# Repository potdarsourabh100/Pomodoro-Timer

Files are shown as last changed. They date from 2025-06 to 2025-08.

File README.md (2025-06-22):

# Pomodoro Timer (STM32 + TM1637 + 18650 Li-ion)

A compact and handheld Pomodoro Timer built using an STM32 microcontroller, TM1637 display, 2 tactile switches, and a buzzer. It is powered by dual 18650 Li-ion cells with a 2S BMS and includes USB charging support.

---

## Pomodoro Timer Flowchart

```text
+----------------------+
|   Start Application |
+----------------------+
           |
           v
+----------------------+
|  Set Work Duration   |<------+
|   (e.g., 25 mins)    |       |
+----------------------+       |
           |                   |
           v                   |
+----------------------+       |
|    Start Work Timer  |       |
+----------------------+       |
           |                   |
           v                   |
+----------------------+       |
|   Countdown Work     |       |
|   Time Every Second  |       |
+----------------------+       |
           |                   |
           v                   |
+----------------------+       |
|  Work Time Finished? |--No--+
+----------------------+
           |
          Yes
           |
           v
+----------------------+
| Play Alarm / Notify |
+----------------------+
           |
           v
+----------------------+
|  Increment Pomodoro  |
|     Count (+1)       |
+----------------------+
           |
           v
+----------------------+
| Pomodoro Count % 4 = 0? |
+----------------------+
       | Yes          | No
       v              v
+----------------+  +----------------------+
| Long Break     |  | Short Break         |
| (15-30 mins)   |  | (5 mins)            |
+----------------+  +----------------------+
       |                   |
       v                   v
+----------------------+  +----------------------+
|  Start Break Timer   |  |  Start Break Timer   |
+----------------------+  +----------------------+
           |                   |
           v                   v
+----------------------+  +----------------------+
| Countdown Break Time |  | Countdown Break Time |
+----------------------+  +----------------------+
           |                   |
           v                   v
+----------------------+  +----------------------+
| Break Time Finished? |  | Break Time Finished? |
+----------------------+  +----------------------+
           |                   |
          Yes                 Yes
           |                   |
           v                   v
+----------------------+
|     Back to Work     |
+----------------------+
           |
           v
     (Repeat Cycle)
```
---

## 🧠 Features

- ⏱️ Pomodoro Mode(P): 25 minutes of focus time
- ☕ Short Break(S): 5 minutes
- 😌 Long Break(L): 15 minutes (after 4 Pomodoros)
- 2 Push Buttons:
  - Button 1: Start/Stop/Reset
  - Button 2: Cycle Modes (P/S/L)
- Buzzer for notifications (end of session, low battery)
- Powered by 2x 18650 Li-ion with BMS protection
- USB Charging (Micro-USB/USB-C)
- TM1637 4-digit 7-segment display

---

## 📦 Hardware Used

| Component | Description |
|---|---|
| STM32 MCU | STM32F0xx / STM32G0xx series |
| Display | TM1637 4-digit 7-segment module |
| Buzzer | Active piezo buzzer |
| Switches | 2x Tactile push buttons |
| Battery | 2x 18650 Li-ion cells |
| USB Charging | TP4056-based charger (5V input) |

---

## 🔧 Build Instructions

1. Assemble all hardware components as per the schematic.
2. Flash the firmware to the STM32 using ST-Link.
3. Power the system using a battery or USB.
4. Use Button 1 to start/stop/reset the timer.
5. Use Button 2 to switch between Pomodoro, Short, and Long Break modes.

---

## 📌 To-Do / Enhancements

- [ ] Add various tones for notifications
- [ ] Add BLE support for app notifications
- [ ] Configurable timer durations via USB
- [ ] Battery monitoring via ADC
- [ ] Low-power sleep mode
- [ ] Pocket-sized, portable enclosure

---

## 📜 License

This project is open-source under the MIT License.

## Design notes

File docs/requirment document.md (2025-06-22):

## 1. Project Overview
A handheld Pomodoro Timer device to help users manage time effectively using the Pomodoro technique. The device will display a countdown timer on a TM1637 4-digit display, accept input through two push buttons, provide audible alerts via a buzzer, and be powered by a rechargeable 2-cell 18650 Li-ion battery with BMS. USB connectivity will be used for charging and data communication.

## 2. Objective
To develop a compact, portable, and user-friendly Pomodoro Timer that offers a simple user interface and effective time tracking with minimal hardware complexity.
```text
+----------------------+
|   Start Application |
+----------------------+
           |
           v
+----------------------+
|  Set Work Duration   |<------+
|   (e.g., 25 mins)    |       |
+----------------------+       |
           |                   |
           v                   |
+----------------------+       |
|    Start Work Timer  |       |
+----------------------+       |
           |                   |
           v                   |
+----------------------+       |
|   Countdown Work     |       |
|   Time Every Second  |       |
+----------------------+       |
           |                   |
           v                   |
+----------------------+       |
|  Work Time Finished? |--No--+
+----------------------+
           |
          Yes
           |
           v
+----------------------+
| Play Alarm / Notify |
+----------------------+
           |
           v
+----------------------+
|  Increment Pomodoro  |
|     Count (+1)       |
+----------------------+
           |
           v
+----------------------+
| Pomodoro Count % 4 = 0? |
+----------------------+
       | Yes          | No
       v              v
+----------------+  +----------------------+
| Long Break     |  | Short Break         |
| (15-30 mins)   |  | (5 mins)            |
+----------------+  +----------------------+
       |                   |
       v                   v
+----------------------+  +----------------------+
|  Start Break Timer   |  |  Start Break Timer   |
+----------------------+  +----------------------+
           |                   |
           v                   v
+----------------------+  +----------------------+
| Countdown Break Time |  | Countdown Break Time |
+----------------------+  +----------------------+
           |                   |
           v                   v
+----------------------+  +----------------------+
| Break Time Finished? |  | Break Time Finished? |
+----------------------+  +----------------------+
           |                   |
          Yes                 Yes
           |                   |
           v                   v
+----------------------+
|     Back to Work     |
+----------------------+
           |
           v
     (Repeat Cycle)
```

## 3. Hardware Requirements
### 3.1 Core Components

|Component	 |Description |
|---|---|
|MCU	 |STM32 (STM32F0xx/G0xx preferred for low power) |
|Display	 |TM1637 4-digit 7-segment display module |
|Switches	 |2 tactile push buttons |  
|Buzzer	 |Active piezo buzzer |
|Battery	 |2 x 18650 Li-ion cells |
|Battery |Protection	2S BMS module |
|Charging	 |Micro-USB or USB-C port with TP4056-based charging IC|

Enclosure	Handheld ergonomic plastic casing (3D printed or off-the-shelf)
## 4. Functional Requirements
### 4.1 Timer Operation
- Pomodoro Duration: 25 minutes of focused work
- Break Duration:
  - Short Break: 5 minutes
  - Long Break: 15 minutes (after every 4 Pomodoros)
- User Input:
  - Button 1 (Start/Stop/Reset):
    - Short Press: Start/Stop timer
    - Long Press (>2s): Reset current session
  - Button 2 (Mode Switch):
- Cycle between Pomodoro, Short Break, Long Break
- Confirmation after 2s timeout or button press
### 4.2 Display Behavior (TM1637)
- Show countdown in MM:SS format.
- Display P, S, or L in the first digit (blinking) to indicate Pomodoro, Short break, or Long break respectively (if applicable).
- When timer is paused, display should blink.
- Show done or ---- when timer ends.
### 4.3 Sound Notifications
- Short beep every minute for feedback (optional).
- Long beep (2s) at the end of each timer.
- Continuous short beeps for 5s as final notification (optional).
### 4.4 Power Management
- Powered by 2x 18650 cells in series.
- 2S BMS to protect from over-voltage, over-discharge, and short-circuit.
- Battery voltage monitoring via ADC to indicate a low battery.
- A low battery warning on display and a buzzer beep pattern.
- Auto shutdown when battery is critically low.
### 4.5 Charging and USB Interface
- USB port for: Charging the batteries (5V input)
- Future provision: serial communication for log extraction or timer configuration
- LED indicator for charging (charging/red, full/green)
### 4.6 Ergonomics
- Device should:
  - Be compact and handheld (approx. 100mm x 60mm x 30mm)
  - Use minimal buttons for ease of use
  - Have an accessible USB port and clear visibility of the display
## 5. Non-Functional Requirements
### 5.1 Performance
- Timer precision: ±1 second over 25 minutes
- Debouncing: Software-based for all buttons
- Startup Time: <2 seconds
- The buzzer should not exceed 80 dB SPL at 10cm
### 5.2 Power Efficiency
- Sleep mode when idle
- Wake up on button press
- Total standby current <500 µA
### 5.3 Environmental
- Operating temperature: 0°C to 50°C
- Humidity: 20–85% RH, non-condensing
## 6. Future Enhancements (Optional)
- Vibration motor for silent notification
- Bluetooth interface for app connectivity
- OLED display for more detailed status
- Custom timer settings via serial interface or USB config tool
## 7. Deliverables
- Schematics and PCB design files
- Firmware source code (with comments and documentation)
- 3D design files for enclosure
- Test report for all functional cases
- User manual (1-page quick start)

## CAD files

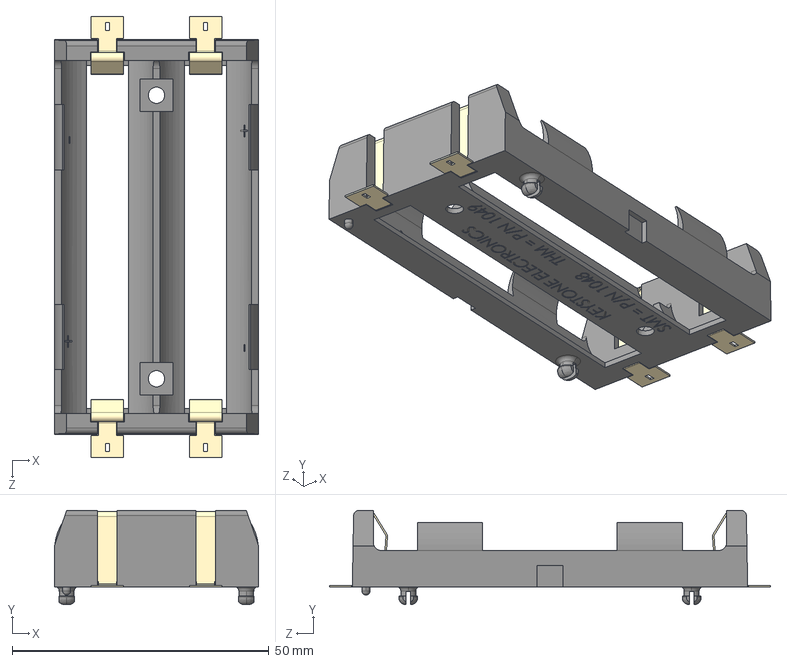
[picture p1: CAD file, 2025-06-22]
hardware/1048/1048.step
39.8 x 18.3 x 86.0 mm

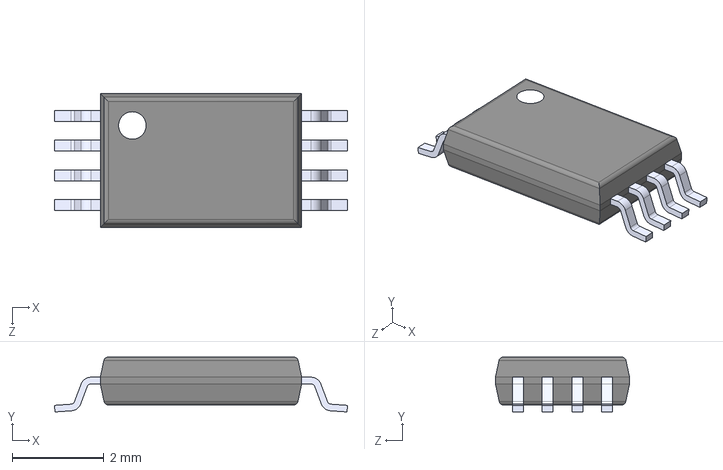
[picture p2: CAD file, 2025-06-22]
hardware/FS8205A/FS8205A.step
6.40 x 1.20 x 2.93 mm

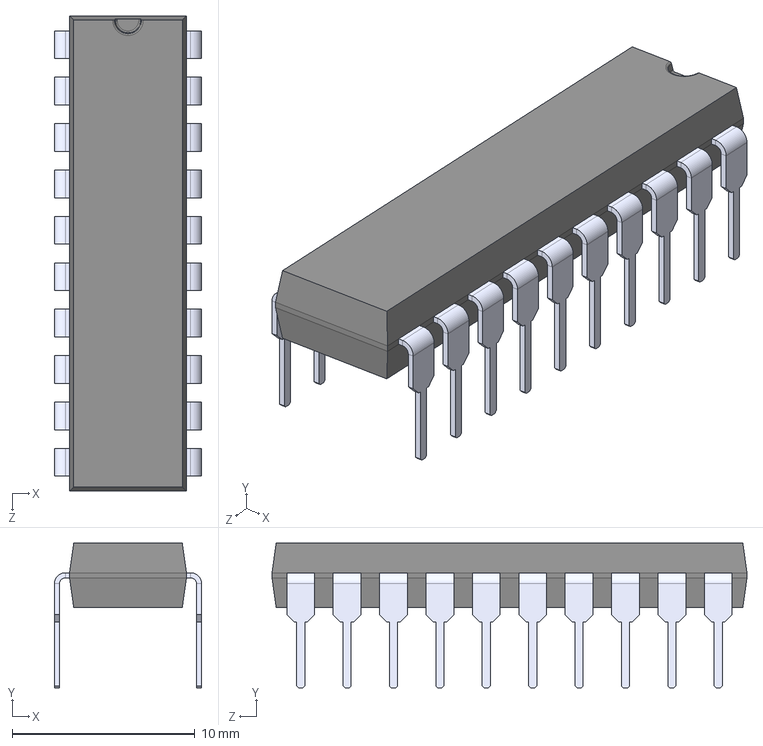
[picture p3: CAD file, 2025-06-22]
hardware/TM1637/TM1637.step
8.06 x 7.91 x 26.0 mm

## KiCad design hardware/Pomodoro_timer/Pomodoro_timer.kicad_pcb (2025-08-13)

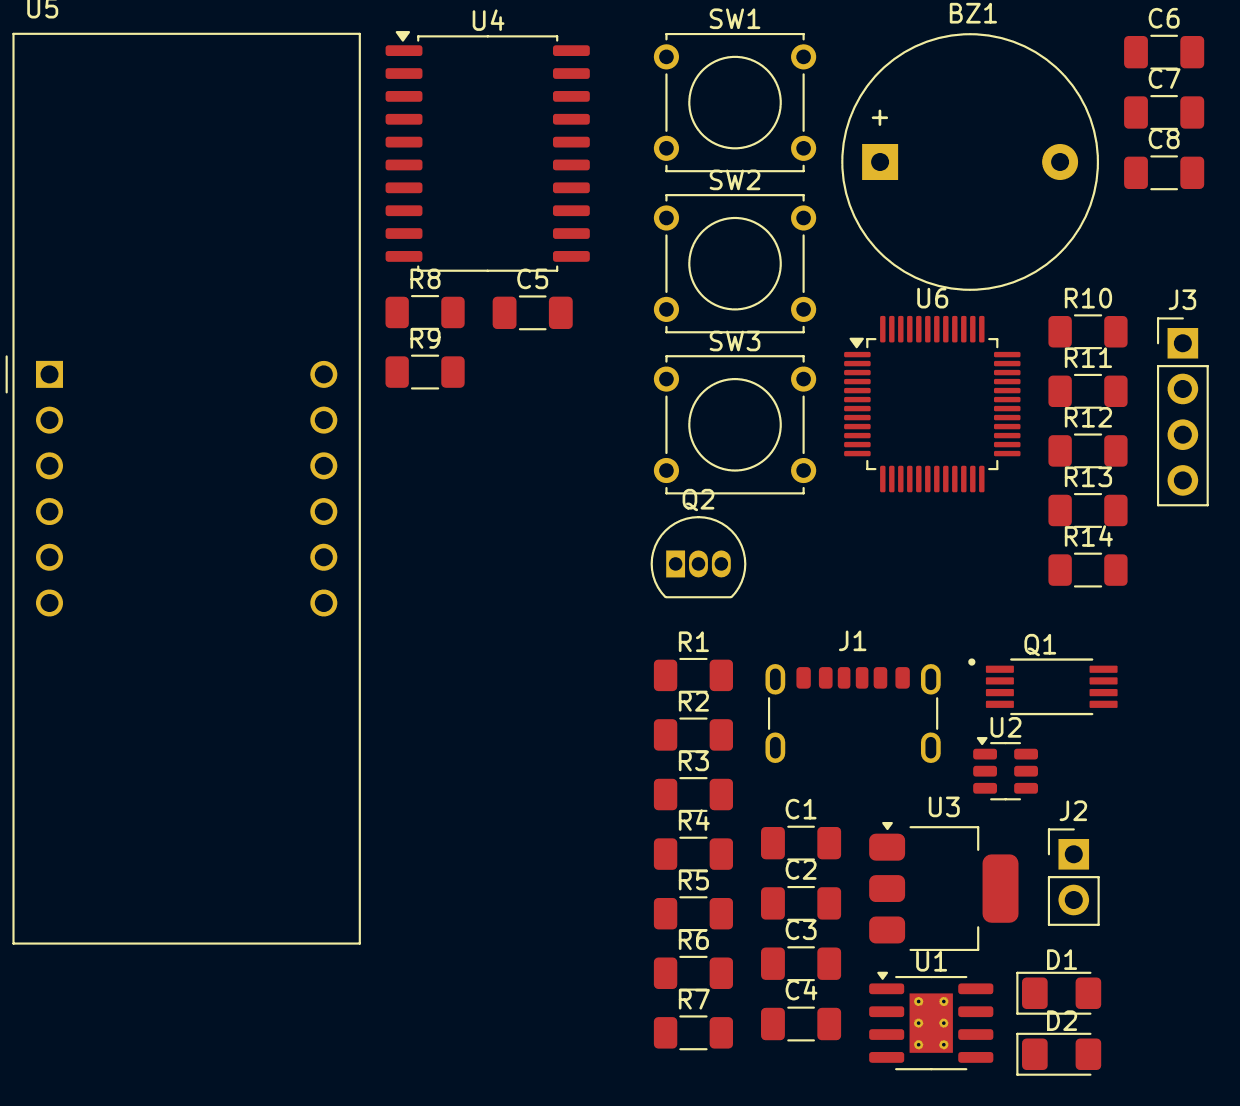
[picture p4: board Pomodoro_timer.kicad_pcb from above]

Board: 2 copper layers, 39 parts (0 on the bottom side), 38 nets, no tracks yet.

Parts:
BZ1: Buzzer; Buzzer_D14mm_H7mm_P10mm
C1, C3, C4, C5, C6, C7, C8: 100nF; C_1206_3216Metric_Pad1.33x1.80mm_HandSolder
C2: 10uF; C_1206_3216Metric_Pad1.33x1.80mm_HandSolder
D1: RED; LED_1206_3216Metric_Pad1.42x1.75mm_HandSolder
D2: GRN; LED_1206_3216Metric_Pad1.42x1.75mm_HandSolder
J1: USB_C_Receptacle_PowerOnly_6P; USB_C_Receptacle_GCT_USB4125-xx-x_6P_TopMnt_Horizontal
J2: Battery; PinHeader_1x02_P2.54mm_Vertical
J3: Prog_Port; PinHeader_1x04_P2.54mm_Vertical
Q1: FS8205A; SOP65P640X120-8N
Q2: BC516; TO-92_Inline
R1, R2: 5K1; R_1206_3216Metric_Pad1.30x1.75mm_HandSolder
R3, R4, R6, R10: 1K; R_1206_3216Metric_Pad1.30x1.75mm_HandSolder
R5: 1K2; R_1206_3216Metric_Pad1.30x1.75mm_HandSolder
R7: 100; R_1206_3216Metric_Pad1.30x1.75mm_HandSolder
R8, R9, R11, R12, R13, R14: 4K7; R_1206_3216Metric_Pad1.30x1.75mm_HandSolder
SW1, SW2: CTRL_SW; SW_Tactile_Straight_KSA0Axx1LFTR
SW3: FUNC_SW; SW_Tactile_Straight_KSA0Axx1LFTR
U1: TP4056-42-ESOP8; SOIC-8-1EP_3.9x4.9mm_P1.27mm_EP2.41x3.3mm_ThermalVias
U2: DW01A; SOT-23-6
U3: AP2127K-3.3; SOT-223-3_TabPin2
U4: TM1637; SOIC-20W_7.5x12.8mm_P1.27mm
U5: CC56-12EWA; CA56-12EWA
U6: STM32G070CBTx; LQFP-48_7x7mm_P0.5mm

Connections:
+5V: C1.1, D1.2 (A), D2.2 (A), J1.A9 (VBUS), J1.B9 (VBUS), U1.4 (V_{CC}), U1.8 (CE)
CLK: R9.2, U4.18 (CLK), U6.26 (PB14)
DIO: R8.2, U4.17 (DIO), U6.27 (PB15)
GND: C1.2, C2.2, C3.2, C4.2, C5.2, C6.2, C7.2, C8.2, J1.A12 (GND), J1.B12 (GND), J1.S1 (SHIELD), J3.4, Q1.6, Q1.7, Q2.3 (E), R1.1, R2.1, R5.1, R6.1, SW1.1, SW2.2, SW3.2, U1.1 (TEMP), U1.3 (GND), U2.6 (GND), U3.2 (GND), U4.1 (GND), U6.7 (VSS)
unnamed: BZ1.2 (-), Q2.1 (C)
unnamed: D1.1 (K), R3.1
unnamed: D2.1 (K), R4.1
unnamed: J1.A5 (CC1), R2.2
unnamed: J1.B5 (CC2), R1.2
unnamed: C3.1, J2.1, R7.1, U1.5 (BAT), U3.1 (VIN), U3.3 (EN)
unnamed: J2.2, Q1.2, Q1.3
unnamed: Q2.2 (B), R10.2
unnamed: R5.2, U1.2 (PROG)
unnamed: R3.2, U1.7 (~CHRG)
unnamed: R4.2, U1.6 (~STDBY)
unnamed: R6.2, U2.2 (CS)
unnamed: Q1.5, U2.3 (OC)
unnamed: Q1.4, U2.1 (OD)
unnamed: C2.1, R7.2, U2.5 (VCC)
unnamed: U4.15 (GRID1), U5.12 (CC1)
unnamed: U4.14 (GRID2), U5.9 (CC2)
unnamed: U4.13 (GRID3), U5.8 (CC3)
unnamed: U4.12 (GRID4), U5.6 (CC4)
unnamed: U4.2 (SEG1/KS1), U5.11 (a)
unnamed: U4.3 (SEG2/KS2), U5.7 (b)
unnamed: U4.4 (SEG3/KS3), U5.4 (c)
unnamed: U4.5 (SEG4/KS4), U5.2 (d)
unnamed: U4.6 (SEG5/KS5), U5.1 (e)
unnamed: U4.7 (SEG6/KS6), U5.10 (f)
unnamed: U4.8 (SEG7/KS7), U5.5 (g)
unnamed: U4.9 (SEG8/KS8), U5.3 (DPX)
unnamed: R12.1, SW1.2, U6.10 (NRST)
unnamed: R14.1, SW2.1, U6.24 (PB12)
unnamed: R13.1, SW3.1, U6.25 (PB13)
unnamed: R10.1, R11.1, U6.3 (PC15)
PWR: BZ1.1 (+), C4.1, C5.1, C6.1, C7.1, C8.1, J3.3, R8.1, R9.1, R11.2, R12.2, R13.2, R14.2, U4.16 (VDD), U6.4 (VBAT), U6.5 (VREF+), U6.6 (VDD)
SWCLK: J3.1, U6.36 (PA14)
SWDIO: J3.2, U6.35 (PA13)

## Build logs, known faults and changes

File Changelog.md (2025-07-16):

# 📓 CHANGELOG

All notable changes to this project will be documented in this file.

---
## [1.2.2] - 2025-07-16
### 🐞 Bug fix
- The values for cycles changed to 5 correct Logic implemented.
### ⚠️ Warning/Notice
- The pause function is yet to be added.
### 💤 Power/Performance
- Although the initial performance looks good
Power-related activities are yet to be tested thoroughly.
---
## [1.2.0] - 2025-07-14
### 🐞 Bug fix
- The given platform dependencies are removed 
- Buzzer functionalities added
### ⚠️ Warning/Notice
- The pause function is yet to be added.
### 💤 Power/Performance
- Although the initial performance looks good
Power-related activities are yet to be tested thoroughly.

## [1.0.1] - 2025-06-22
### 🐞 Bug fix
- The timer was not performing in the correct mode in the proper order
fixed
### ⚠️ Warning/Notice
- Button-related activities are started.
- The pause function is yet to be added.
- Buzzer hardware not yet added.
### 💤 Power/Performance
- Although the initial performance looks good
Power-related activities are yet to be tested thoroughly.

## [1.0.0] - 2025-06-22
### 🚀 Initial Release
- Core Pomodoro functionality (25/5/15 minute cycles)
### ⚠️ Warning/Notice
- Button-related activities are started.
- The pause function is yet to be added.
- Buzzer hardware not yet added.
### 💤 Power/Performance
- Although the initial performance looks good
Power-related activities are yet to be tested thoroughly.

## Legend

| Emoji  | Meaning |
|---|---|
| ✨ | New feature |
| 🛠️ | Change/Improvement|
| 🐞 | Bug fix |
| 🚀 | Major release |
| ⚠️ | Warning/Notice |
| 💤 | Power/Performance |
| 🔧 | Refactor/Tooling  |

---

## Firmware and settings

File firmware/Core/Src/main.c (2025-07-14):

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
/* Includes ------------------------------------------------------------------*/
#include "main.h"

TIM_HandleTypeDef htim3;

void SystemClock_Config(void);
static void MX_GPIO_Init(void);
static void MX_TIM3_Init(void);
/**
  * @brief  The application entry point.
  * @retval int
  */
int main(void)
{

  /* MCU Configuration--------------------------------------------------------*/

  /* Reset of all peripherals, Initializes the Flash interface and the Systick. */
  HAL_Init();

  /* Configure the system clock */
  SystemClock_Config();

  /* Initialize all configured peripherals */
  MX_GPIO_Init();
  MX_TIM3_Init();
  /* USER CODE BEGIN 2 */

  HAL_Delay(1000);

  /* Set LED for warning */
  HAL_GPIO_WritePin(GPIOC, GPIO_PIN_13, GPIO_PIN_SET);

  /* Set Buzzer OFF*/
  HAL_GPIO_WritePin(GPIOB, GPIO_PIN_9, GPIO_PIN_SET);

  userMain();
  /* USER CODE END 2 */

  /* Infinite loop */
  /* USER CODE BEGIN WHILE */
  while (1)
  {
    /* USER CODE END WHILE */

    /* USER CODE BEGIN 3 */
	  /* The given LED reaches if application functions crashed*/
	  HAL_GPIO_TogglePin(GPIOC, GPIO_PIN_13);
	  HAL_Delay(2000);
  }
  /* USER CODE END 3 */
}

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


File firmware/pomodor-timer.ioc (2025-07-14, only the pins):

Mcu.UserName=STM32F401CCUx
PA0-WKUP.Signal=GPIO_Input
PA1.Signal=GPIO_Input
PA13.Signal=SYS_JTMS-SWDIO
PA14.Signal=SYS_JTCK-SWCLK
PB12.Signal=GPIO_Output
PB13.Signal=GPIO_Output
PB9.Signal=GPIO_Output
PC13-ANTI_TAMP.Signal=GPIO_Output

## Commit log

2025-04-20 Given firmware added with TM1637 drivers & tested with 1 second timer.
2025-04-21 Basic timer functionalities & button operations are verified
2025-04-22 POC verified moving to Hardware design
    [Pomodoro_timer.kicad_pcb, Pomodoro_timer.kicad_sch]
2025-06-22 All pieces for prototype are designed & soldered on PCB.
    The given hardware is working with code.
2025-06-22 ## [1.0.0] - 2025-06-22
    ### 🚀 Initial Release
    - Core Pomodoro functionality (25/5/15 minute cycles)
    ---
    ### ⚠️ Warning/Notice
    - Button-related activities are started.
    - The pause function is yet to be added.
    - Buzzer hardware not yet added.
    ### 💤 Power/Performance
    - Although initial performance looks good
    Power-related activities are yet to be tested thoroughly.
    [main.c, pomodorotimer.c]
2025-06-22 ## [1.0.1] - 2025-06-22
    ### 🐞 Bug fix
    - The timer was not performing correct mode in the proper order
    fixed
    - Although the initial performance looks good
    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
    [pomodorotimer.c]
2025-06-22 Board designing started
    [FS8205A.step, Pomodoro_timer.kicad_sch, Power_Supply.kicad_sch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]
2025-06-22 TM1637 Design started
    [1048.step, Power_Supply.kicad_sch, TM1637.step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]
2025-07-14 ## [1.2.0] - 2025-07-14
    - The given platform dependencies are removed
    - Buzzer functionalities added
    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
    [main.c, pomodor-timer.ioc, pomodorotimer.c]
2025-07-16 ## [1.2.2] - 2025-07-16
    - The values for cycles changed to 5 correct Logic implemented.
    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
    [pomodorotimer.c]
2025-08-04 PCB Ver.A : The Schematic completed the next part for PCB can be started.
    [Pomodoro_timer.kicad_sch, Power_Supply.kicad_sch, TM1637_Display.kicad_sch]
2025-08-06 PCB Ver.A The required changes were not in line So made few alterations Need to start again
    [Pomodoro_timer.kicad_sch, Power_Supply.kicad_sch, TM1637_Display.kicad_sch]
2025-08-13 PCB Ver.A All changes finalized & PCB design has been started
    [MCU_Misc.kicad_sch, Pomodoro_timer.kicad_pcb, Pomodoro_timer.kicad_sch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]

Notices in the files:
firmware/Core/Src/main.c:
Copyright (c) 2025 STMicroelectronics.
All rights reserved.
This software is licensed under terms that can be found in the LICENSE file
